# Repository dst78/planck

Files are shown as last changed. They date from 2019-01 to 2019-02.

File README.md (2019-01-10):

# Planck - Auduino Modular Synth Concept

granular-esque VCO based on the [Auduino](https://code.google.com/archive/p/tinkerit/wikis/Auduino.wiki) for the eurorack format

## general outline
Planck processes two triangle waves to a grain. Both waves can be manipulated in terms of frequency and decay in order to achieve various harmonics. Note that manipulation of the grain frequencies does *not* affect the frequency of the output, only the harmonics.

The module allows for manual setting of an output frequency via potentiometer or CV input. 

What sets this module appart from the original Auduino is the addition of chaos.

## chaos
The triangle wave frequencies can be indirectly modulated (but not controlled) through external chaos triggers. Again, this only affects the grain harmonics, not the output frequency.

What is happening internally is that once a chaos trigger is received, one random value is generated for each triangle wave. This value is shifting the wave frequency up or down, resulting in different grain harmonics.

The chaos amount knob on the panel allows you to adjust how much chaos affects the grain wave frequencies, down to turning the effect off completely. The Planck VCO also comes with a CV input for external control of the chaos amount.

When no trigger signal is plugged into the trigger input, a new chaos trigger is generated internally whenever the V/Oct input changes rapidly by at least one semitone. The internal chaos trigger is normalled to the chaos trigger jack on the panel. When a trigger is plugged into the chaos trigger jack on the panel, the internal triggers have no effect and the generation of new chaos values is completely controlled externally.

## hardware notes
Since this module is Arduino based, all input/outputs have been voltage limited via Schottky diodes to 0-5V. 

**There is no protection against connecting in the power supply cable incorrecting.**

## A note on tuning
Due to variance in the frequency crystals of individual Arduinos it is likely that you have to tune your module before it is usable. You can do this by following the instructions outlined in the README inside the freqGen folder.

## What's in the name?
The module was named in honor of Max Planck and as a reference to the Planck-length.

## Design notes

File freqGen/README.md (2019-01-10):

# Frequency tuning
This file describes how to generate custom-tuning for your module. This is necessary when your Arduinos frequency quartz is slightly off or just to get a different frequency range.

The original code was found on [Ginko Synthese](http://www.ginkosynthese.com/product/grains/) but this version is highly adapted. The underlying formula remains the same however.

## Background
Due to variance in an individual Arduinos' frequency crystal it is somewhat likely that you will have to tune your Planck VCO.

I'm providing a solution to this by means of generating custom voltage-to-octave PWM frequency tables. You will need a C compiler on your computer that works from the commandline. Since Planck is an Arduino project, chances are that this is already the case. Note however that I won't be able to support you with setting this up, sorry.

## How you tune the Arduino
The V/Oct mapping relies on a base note and a base increment.

The base note defines what you hear when Planck receives exactly 0 volts via the V/Oct input jack.

*The default value for this is C1, or 32.7 Hertz.*

The base incement defines how much the frequency increases per voltage increment. With a perfect quartz crystal this would be one octave per volt.

*The underlying mathematical default for this is 2.0.*

### Step one: Test your tuning
The values in the vOctTable.h file are tuned to my personal quartz, they may or may not work with yours. (32.66 Hertz base note and 1.955 base increment)

To test the tuning of your Planck, send precisely known voltages to the V/Oct jack and check the generated note with a tuner or a guitar tuner app for your smartphone.

If your Planck VCO is out of tune, continue with...

### Step two: compile the custom tuner
- open the commandline and move to the freqGen subdirectory
- call 'make'
- you should have a genVOctTable executable now.

### Step three: Tune the base note C1

The 'clean' base note has a frequency of 32.7 Hertz. You can generate frequency tables with a different base note by calling

./genVOctTable -n [your_base_note]

So for a base note of 32.6 Hertz you'd call
./genVOctTable -n 32.6

...and the vOctTable.h file in the main directory would be rewritten with that value.

To find the right value for you is a bit of trial and error. In detail:

- Send a precise zero Volts signal to the V/Oct input.
- Call ./genVOctTable -n [your_base_note] as described above
- Recompile the Arduino project and upload the sketch.
- Test the tuning again.

Rinse and repeat until the base note is in tune. Due to the resolution of the PWM signal you may not get this perfect and the note might remain a few cents off.

Once the base note is tuned, see if other notes are in tune or not. If you experience frequency drift between zero and five volts then continue with...

### Step four: Tune the frequency compensation

The other parameter that genVOctTable can manipulate is what I call the base increment. The frequency-per-volt rises as a function of 2.0^v (two to the power of v) where v is the voltage, assuming a perfect frequency crystal.

If yours is slightly fast or slow, you need to adjust the 2.0 part of the equation. To do this:

- Call ./genVOctTable -n [your_base_note] -i [your_increment]
- Change [your_increment] from 2.0 to 1.95 or something small like that. The frequency table is very sensitive to small changes.
- Recompile the Arduino project and upload the sketch.

Now feed known voltages to Planck and see if the frequency drift improves.
Rinse and repeat until the frequency drift is eliminated.

Voila, you now have a tuned granular oscillator.

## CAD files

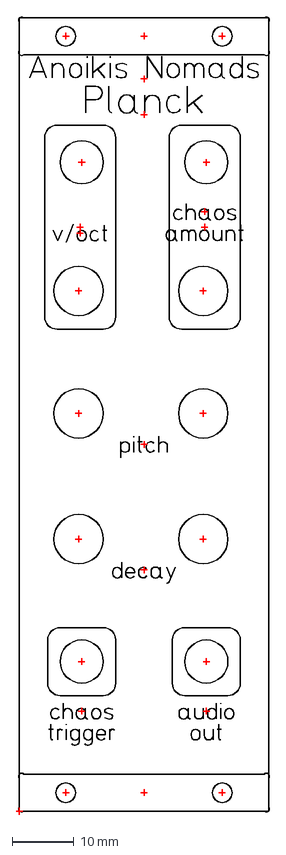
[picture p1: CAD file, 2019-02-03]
eurorack panel/Planck.dxf
41.0 x 129.1 mm

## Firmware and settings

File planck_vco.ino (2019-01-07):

/**
 * Anoikis Nomads :: Planck
 * 
 * 
 * A granular-synthesis VCO for the Eurorack format, based on the 
 * Auduino Synthesizer v5 by Peter Knight http://tinker.it
 * 
 * 
 * All information on Planck is on https://github.com/dst78/planck
 * 
 * 
 * Released under Creative Commons Attribution-ShareAlike 3.0 Unported
 * https://creativecommons.org/licenses/by-sa/3.0/deed.de
 * 
 * 
 * Information about the original Auduino:
 * help:      http://code.google.com/p/tinkerit/wiki/Auduino
 * more help: http://groups.google.com/group/auduino
 * 
 * The voltage-per-octave mapping was derived from a code found on
 * http://www.ginkosynthese.com/product/grains/ which is another Auduino
 * derivative for Eurorack.
 */
#include <avr/io.h>
#include <avr/interrupt.h>

/** 
 * V/Oct frequency mapping
 */
#include "vOctTable.h"

/** 
 * In case you want to use other note mappings, check the options in the .h 
 * file below. 
 * 
 * You will need to replace the line
 *    syncPhaseInc = mapFreq(analogNote);
 * in the loop() function with whatever mapping function you'll use.
 * 
 * In its default state, the code below doesn't use the noteTables.h at all but
 * since the compiler optimizes it away there is no point in removing the include.
 */
#include "noteTables.h"

// *******************************************************************************
/**
 * Set to true to activate the LED for chaos trigger debugging.
 */
#define DEBUG false
/**
 * Set to true if you want to enable internal chaos triggers.
 * 
 * These are generated whenever a V/Oct change of more than a semitone is detected.
 */
#define USE_INTERNAL_CHAOS true

uint16_t syncPhaseAcc;
uint16_t syncPhaseInc;

uint16_t grain1PhaseAcc;
uint16_t grain1PhaseInc;
uint16_t grain1Amp;
uint8_t  grain1Decay;

uint16_t grain2PhaseAcc;
uint16_t grain2PhaseInc;
uint16_t grain2Amp;
uint8_t  grain2Decay;

/**
 * length of interpolation between chaos-corrected grain frequencies.
 * feel free to increase this for a more gradual change (or connect to another pot / jack for CV control)
 */
#define CHAOS_INTERPOLATION_STEPS 50  

/** 
 * adjust these if you want a different range for maximum chaos. minimum chaos is always 0.
 */
#define CHAOS_AMOUNT_MIN -150
#define CHAOS_AMOUNT_MAX 150

/**
 * Change in millivolts that is required to trigger the internal chaos flag.
 * 
 * One semitone == 1024 / 5 / 12 = 17.0666666 Volts
 */
#define INTERNAL_CHAOS_THRESHOLD 17



// current chaos amount as per potentiometer / CV
int previousNote;
uint8_t chaosAmount;
int16_t chaosVal1, oldChaosVal1, newChaosVal1;
int16_t chaosVal2, oldChaosVal2, newChaosVal2;
// interpolates between old and new chaos values for a smoother experience
uint8_t chaosInterpolationStep; 
// interrupt routine flag
volatile boolean readChaos = false;
// for debugging
#if DEBUG
volatile byte ledState = LOW;
#endif

// Map analogue & digital channels
#define SYNC_CONTROL         A4
#define GRAIN1_FREQ_CONTROL  A0
#define GRAIN1_DECAY_CONTROL A2
#define GRAIN2_FREQ_CONTROL  A3
#define GRAIN2_DECAY_CONTROL A1

#define CHAOS_AMOUNT         A5
#define CHAOS_TRIG_INT       PD7
#define CHAOS_TRIG_EXT       PD2

#if defined(__AVR_ATmega8__)
//
// On old ATmega8 boards.
//    Output is on pin 11
//
#define LED_PIN       13
#define PWM_PIN       11
#define PWM_VALUE     OCR2
#define PWM_INTERRUPT TIMER2_OVF_vect
#elif defined(__AVR_ATmega1280__)
//
// On the Arduino Mega
//    Output is on pin 3
//
#define LED_PIN       13
#define PWM_PIN       3
#define PWM_VALUE     OCR3C
#define PWM_INTERRUPT TIMER3_OVF_vect
#else
//
// For modern ATmega168 and ATmega328 boards
//    Output is on pin 3
//
#define LED_PIN       13
#define PWM_PIN       3
#define PWM_VALUE     OCR2B
#define PWM_INTERRUPT TIMER2_OVF_vect
#endif

/**
 * Arduino setup routine
 */
void setup() {
  // needed for the internal chaos trigger
  randomSeed(analogRead(1));

  // set up PWM audio out
  pinMode(PWM_PIN, OUTPUT); 
  audioOn();

  #if DEBUG
  pinMode(LED_PIN, OUTPUT);
  #endif

  // configure chaos pins and interrupts
  pinMode(CHAOS_TRIG_INT, OUTPUT);
  pinMode(CHAOS_TRIG_EXT, INPUT_PULLUP);
  
  attachInterrupt(digitalPinToInterrupt(CHAOS_TRIG_EXT), handleChaosTrigger, RISING);
  chaosVal1   = 0;
  chaosVal2   = 0;
  chaosAmount = 0;
}

/**
 * main loop
 */
void loop() {

  // read V/Oct
  int analogNote = analogRead(SYNC_CONTROL);

  #if USE_INTERNAL_CHAOS
  // detect changes larger than a semitone
  int diff = analogNote - previousNote;
  
  if (abs(diff) > INTERNAL_CHAOS_THRESHOLD) {
    triggerInternalChaos();
    previousNote = analogNote;
  }
  #endif
    
  // new chaos trigger has been received, read chaos amount and process the new values
  if (readChaos) {
    readChaos = false; // reset flag
    
    uint16_t val = analogRead(CHAOS_AMOUNT);
  
    // hysteresis for the potentiometer
    if (val > 100) {
      chaosInterpolationStep = 0;
      chaosAmount = map(val, 0, 1024, 0, 100); // map voltage to percent
      oldChaosVal1 = newChaosVal1;
      oldChaosVal2 = newChaosVal2;
      // generate new chaos values, dampened by chaosAmount
      newChaosVal1 = (random(CHAOS_AMOUNT_MIN, CHAOS_AMOUNT_MAX) * chaosAmount) / 100;
      newChaosVal2 = (random(CHAOS_AMOUNT_MIN, CHAOS_AMOUNT_MAX) * chaosAmount) / 100;
      
    } else {
      // ensure chaos values are zero to let the original sound through
      chaosVal1 = 0;
      chaosVal2 = 0;
    }
  }

  // use linear interpolation to change from old chaos values to new ones
  if (chaosInterpolationStep < CHAOS_INTERPOLATION_STEPS) {
    chaosVal1 = map(chaosInterpolationStep, 0, CHAOS_INTERPOLATION_STEPS, oldChaosVal1, newChaosVal1);
    chaosVal2 = map(chaosInterpolationStep, 0, CHAOS_INTERPOLATION_STEPS, oldChaosVal2, newChaosVal2);
    chaosInterpolationStep++;
  }

  #if DEBUG
  digitalWrite(LED_PIN, ledState);
  #endif

  // syncPhaseInc is the increment of progression through a grain
  syncPhaseInc = mapFreq(analogNote);

  // read grain variables, apply chaos
  grain1PhaseInc = mapPhaseInc(constrain(chaosVal1 + analogRead(GRAIN1_FREQ_CONTROL), 0, 1023)) / 2;
  grain2PhaseInc = mapPhaseInc(constrain(chaosVal2 + analogRead(GRAIN2_FREQ_CONTROL), 0, 1023)) / 2;
  grain1Decay    = analogRead(GRAIN1_DECAY_CONTROL) / 8;
  grain2Decay    = analogRead(GRAIN2_DECAY_CONTROL) / 4;
}

/**
 * initializes the timer interrupt for audio PWM output
 */
void audioOn() {
#if defined(__AVR_ATmega8__)
  // ATmega8 has different registers
  TCCR2 = _BV(WGM20) | _BV(COM21) | _BV(CS20);
  TIMSK = _BV(TOIE2);
#elif defined(__AVR_ATmega1280__)
  TCCR3A = _BV(COM3C1) | _BV(WGM30);
  TCCR3B = _BV(CS30);
  TIMSK3 = _BV(TOIE3);
#else
  // Set up PWM to 31.25kHz, phase accurate
  TCCR2A = _BV(COM2B1) | _BV(WGM20);
  TCCR2B = _BV(CS20);
  TIMSK2 = _BV(TOIE2);
#endif
}

/**
 * PWM interrupt timer
 * 
 * This does the heavy lifting of calculating the PWM value for audio
 */
SIGNAL(PWM_INTERRUPT) {
  uint8_t value;
  uint16_t output;

  syncPhaseAcc += syncPhaseInc;
  if (syncPhaseAcc < syncPhaseInc) {
    // Time to start the next grain
    // this is because syncPhaseAcc did overflow (16 bit = 66535)
    grain1PhaseAcc = 0;
    grain1Amp = 0x7fff;
    grain2PhaseAcc = 0;
    grain2Amp = 0x7fff;
  }

  // Increment the phase of the grain oscillators
  grain1PhaseAcc += grain1PhaseInc;
  grain2PhaseAcc += grain2PhaseInc;

  // Convert phase into a triangle wave
  value = (grain1PhaseAcc >> 7) & 0xff;
  if (grain1PhaseAcc & 0x8000) {
    value = ~value;
  }
  // Multiply by current grain amplitude to get sample
  output = value * (grain1Amp >> 8);

  // Repeat for second grain
  value = (grain2PhaseAcc >> 7) & 0xff;
  if (grain2PhaseAcc & 0x8000) {
    value = ~value;
  }
  output += value * (grain2Amp >> 8);

  // Make the grain amplitudes decay by a factor every sample (exponential decay)
  // this is exponential because of the binary bitshift right
  // grain1Decay and grain2Decay are values from potentiometers
  grain1Amp -= (grain1Amp >> 8) * grain1Decay;
  grain2Amp -= (grain2Amp >> 8) * grain2Decay;

  // Scale output to the available range, clipping if necessary
  output >>= 9;
  if (output > 255) {
    output = 255;
  }

  // Output to PWM (this is faster than using analogWrite)
  PWM_VALUE = output;
}

/**
 * chaos interrupt handler
 * 
 * calculates new grain frequency offset based on chaos value
 */
void handleChaosTrigger() {
  readChaos = true;
  digitalWrite(CHAOS_TRIG_INT, LOW);
  #if DEBUG
  ledState = !ledState;
  #endif
}

/**
 * Sets the internal chaos trigger pin high. This will be picked up by the chaos
 * interrupt handler and chaos will be processed as normal.
 * 
 * Strictly speaking this function is superfluous and simply setting readChaos = true
 * would do the job but this approach opens the trigger up to the outside, should
 * anyone including me change the schematic later. 
 */
void triggerInternalChaos() {
  digitalWrite(CHAOS_TRIG_INT, HIGH);
}

//--------------------------------------------------------------
// various mapper functions to map volts to musical scales
// the frequency arrays can be found in noteTables.h
//--------------------------------------------------------------


/**
 * maps an input voltage to a V/Oct scale
 * 
 * The PWM frequencies are found in vOctTable.h and can be customized through the C code in the ./freqGen subfolder.
 */
uint16_t mapFreq(uint16_t input) {
  return pgm_read_word_near(freqTable + input);
}

/** 
 * Smooth logarithmic mapping  
 * 
 * used in the grain decay calculation
 */
uint16_t antilogTable[] = {
  64830, 64132, 63441, 62757, 62081, 61413, 60751, 60097, 59449, 58809, 58176, 57549, 56929, 56316, 55709, 55109,
  54515, 53928, 53347, 52773, 52204, 51642, 51085, 50535, 49991, 49452, 48920, 48393, 47871, 47356, 46846, 46341,
  45842, 45348, 44859, 44376, 43898, 43425, 42958, 42495, 42037, 41584, 41136, 40693, 40255, 39821, 39392, 38968,
  38548, 38133, 37722, 37316, 36914, 36516, 36123, 35734, 35349, 34968, 34591, 34219, 33850, 33486, 33125, 32768
};

/**
 * maps voltages to logarithmic values
 */
uint16_t mapPhaseInc(uint16_t input) {
  return (antilogTable[input & 0x3f]) >> (input >> 6);
}

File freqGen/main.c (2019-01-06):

#include <stdio.h>
#include <stdlib.h>
#include <unistd.h>
#include <math.h>

/**
 * This routine generates the PWM values to represent voltage-per-octave
 * notes. 
 *
 * The Arduino clock is driven by a 16MHz quartz crystal. Variance between
 * individual quartzes may make it necessary for you to tune your Auduino.
 *
 * You can use the compiled executable from this file to tune.
 *
 * Refer to the how to tune section in the readme for details.
 */
const float BASE_NOTE = 32.7; 
const float BASE_INCR = 2.0;  

int main(int argc, char *argv[]) { 
  int opt;
  float baseNote = BASE_NOTE;
  float baseIncr = BASE_INCR;
  char *fileName = "../vOctTable.h";
  char confirm[3];
  FILE *f;
    
  // parse command line arguments
  while((opt = getopt(argc, argv, "i:n:f:")) != -1) {  
    switch(opt) {  
      case 'n':  
        baseNote = atof(optarg);
        break;  
      case 'i':  
        baseIncr = atof(optarg); 
        break;  
      case 'f':
        fileName = optarg;
        break;
      case ':':  
        printf("option needs a value\n");
        return 1;
        break;  
      case '?':  
        printf("unknown option: %c\n", optopt); 
        return 1;
        break;  
    } 
  }
  
  // confirmation
  printf("\n");
  printf("will generate PWM values based on the follwing settings:\n");
  printf("base note: %.3f\tdefault is %.3f\n", baseNote, BASE_NOTE);  
  printf("base incr: %.4f\tdefault is %.4f\n", baseIncr, BASE_INCR); 
  printf("writing PWM values to\t%s\n", fileName);
  printf("\nContinue? [yN]: ");
  
  fflush(stdin);
  fgets(confirm, 2, stdin);
  
  if (confirm[0] != 'y' && confirm[0] != 'Y') {
    printf("exiting...");
    return 0;
  }
  
  f = fopen(fileName, "w");
  
  if (f == NULL) {
    printf("error writing to file!\n");
    return 1;
  }
  
  fprintf(f, "// custom tuning\n");
  fprintf(f, "// baseNote used: %.4f\n", baseNote);
  fprintf(f, "// baseIncr used: %.4f\n", baseIncr);
  fprintf(f, "const uint16_t freqTable[] PROGMEM = {\n");

  for (int c = 0; c < 1024; c++) {
    float freq = 5 * c / 1024.0;

    fprintf(f, "%.0f, ", floor((65536 * baseNote * pow(baseIncr, freq)) / 31250 + 0.5f)); 

    if (c % 10 == 0) {
      fprintf(f, "\n");
    }
  }

  fprintf(f, "\n};");
  fclose(f);

  return 0;
} 

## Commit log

2019-01-06 added arduino code
2019-01-06 added circuitry
2019-01-06 cleared up eurorack panel folder
    [Planck.dxf]
2019-01-06 added licensing info to circuit svg
2019-01-06 added label for the Arduino Nano
2019-01-06 fixed stripboard orientation for arduino board
2019-01-06 non-functional change to the representation of the wiring (no functional change)
2019-01-06 fixed the volts-to-octave frequency compensation for my personal crystal
    [main.c]
2019-01-06 fixed tabs in c file
    [main.c]
2019-01-07 fixed incorrect assignment of old chaos value 2 when new chaos trigger is received
    [planck_vco.ino]
2019-02-03 updated Eurorack panel, added silkscreen
    [Planck.dxf]
